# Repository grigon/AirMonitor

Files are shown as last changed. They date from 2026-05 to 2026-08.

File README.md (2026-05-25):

# 🌬️ DIY Air Quality Monitor with Bambu Lab Print Correlation

A self-hosted air quality monitoring station built to track how 3D printing affects indoor air. Measures PM2.5, VOC, and NOx in real time — with live correlation to Bambu Lab printer activity via its local MQTT API.

Built for a flat where a Bambu Lab P2S runs PETG and other filaments regularly.

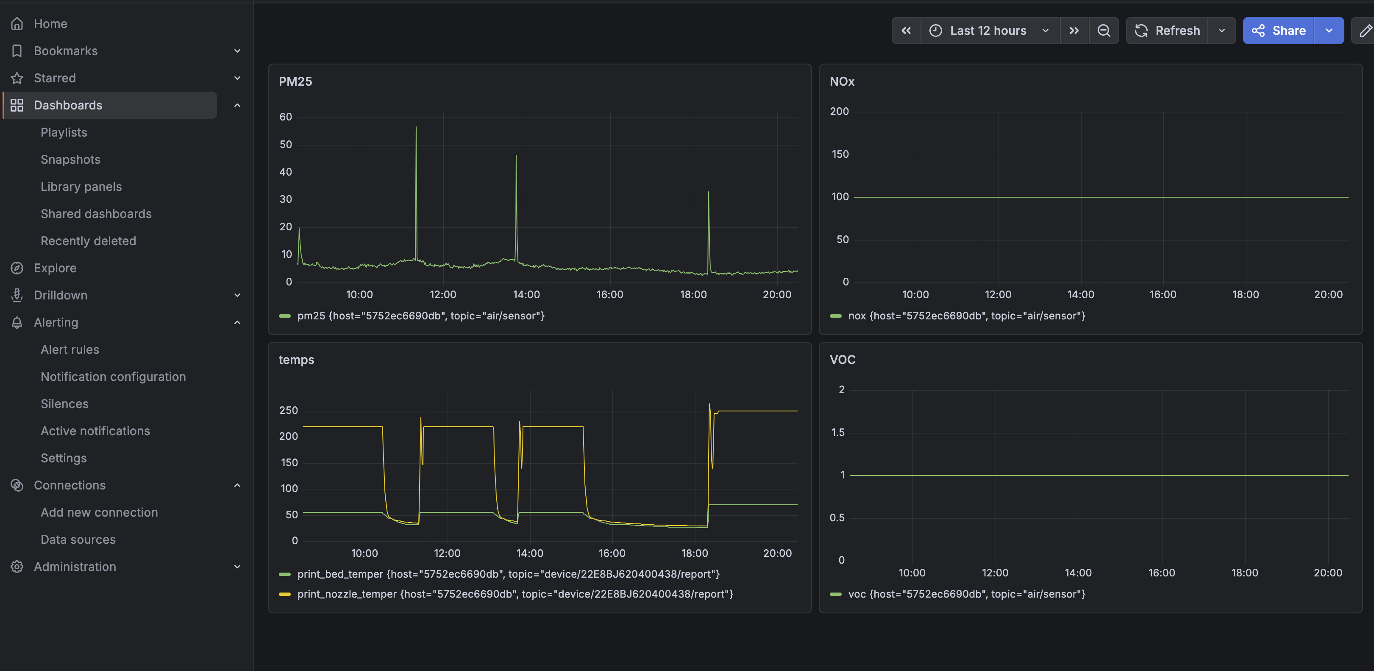
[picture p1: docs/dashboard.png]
Dashboard


---

## Features

- Real-time **PM2.5, PM4, PM10, PM1** via Sensirion SPS30
- **VOC Index and NOx Index** via Sensirion SGP41
- **Bambu Lab printer correlation** — overlays print progress, nozzle/bed temperature with air quality data
- **Email alerts** when air quality thresholds are exceeded
- Fully self-hosted: MQTT → Telegraf → InfluxDB → Grafana
- Runs on a Raspberry Pi with OpenMediaVault (or any Linux server with Docker)

---

## Hardware

| Component | Purpose | Approx. Cost |
| --- | --- | --- |
| ESP32-WROOM-32U (with external antenna) | Microcontroller + WiFi | ~$5 |
| Sensirion SPS30 | Particulate matter (PM1/2.5/4/10) | ~$25 |
| Sensirion SGP41 | VOC + NOx gas sensor | ~$15 |
| External 2.4GHz antenna + U.FL cable | Stable WiFi | ~$3 |
| Breadboard + dupont cables | Prototyping | ~$3 |

> **Note:** For a permanent installation, solder all connections. Loose breadboard connections are a common source of crashes.

---

## Architecture

```
ESP32 (SPS30 + SGP41)
        │
        ▼ MQTT (air/sensor)
Mosquitto Broker ◄──── Bambu Lab P2S (MQTT over SSL)
        │
        ▼
    Telegraf
        │
        ▼
    InfluxDB
        │
        ▼
    Grafana (dashboards + alerts)
```

---

## Wiring

### SGP41 → ESP32 (I2C)

| SGP41 Pin | ESP32 Pin |
| --- | --- |
| VIN | 3.3V |
| GND | GND |
| SDA | GPIO 21 |
| SCL | GPIO 22 |

### SPS30 → ESP32 (I2C via JST ZH 1.5mm 5-pin cable)

| SPS30 Pin | Color (standard cable) | ESP32 Pin |
| --- | --- | --- |
| 1 – VDD | Black | **5V (VIN)** ⚠️ |
| 2 – SDA | Red | GPIO 21 |
| 3 – SCL | White | GPIO 22 |
| 4 – SEL | Yellow | GND (selects I2C mode) |
| 5 – GND | Orange | GND |

> ⚠️ SPS30 requires **5V** on VDD. Both SDA/SCL lines are 3.3V compatible — no level shifter needed.
> ⚠️ Pin 1 color may vary between cable batches. Always verify pin 1 marking (triangle) on the JST connector.

Both sensors share the same I2C bus (GPIO 21/22). I2C addresses:

- SPS30: `0x69`
- SGP41: `0x59`

---

## Software Setup

### 1. Prerequisites

- Docker and Docker Compose installed on your server
- Arduino IDE with ESP32 board support

### 2. Arduino Libraries

Install via Arduino IDE → Library Manager:

- `sps30` by Paul van Haastrecht
- `Sensirion I2C SGP41`
- `Sensirion Core`
- `Sensirion Gas Index Algorithm`
- `PubSubClient`

### 3. Configure and Flash ESP32

Edit `arduino/air_monitor.ino` and set your credentials:

```cpp
const char* ssid = "YOUR_WIFI_SSID";
const char* password = "YOUR_WIFI_PASSWORD";
// ...
mqttClient.setServer("YOUR_SERVER_IP", 1883);
```

Upload to ESP32 via Arduino IDE (`Tools → Board → ESP32 Dev Module`).

### 4. Server Setup (Docker)

Copy `docker/docker-compose.yml` to your server and start services:

```bash
docker compose up -d
```

This starts:

- **Mosquitto** MQTT broker on port 1883
- **InfluxDB 2** on port 8086
- **Grafana** on port 3000
- **Telegraf** data collector

### 5. Configure Mosquitto

Allow anonymous connections (for local network use):

```bash
docker exec -it <mosquitto-container> sh
echo -e "listener 1883\nallow_anonymous true" > /mosquitto/config/mosquitto.conf
exit
docker restart <mosquitto-container>
```

### 6. Configure InfluxDB

1. Open `http://YOUR_SERVER_IP:8086`
2. Create an account, organization (e.g. `home`), and bucket (e.g. `air`)
3. Generate an API token and copy it

### 7. Configure Telegraf

Edit `config/telegraf.conf` with your InfluxDB token, organization, and bucket.

For Bambu Lab integration, add your printer's IP, serial number, and access code (found in printer Settings → Network → LAN Mode).

Restart Telegraf after any config change:

```bash
docker restart <telegraf-container>
```

### 8. Grafana Setup

1. Open `http://YOUR_SERVER_IP:3000` (default: admin/admin)
2. Add InfluxDB as a data source:
   - Query Language: **Flux**
   - URL: `http://influxdb:8086`
   - Organization, token, and default bucket from step 6
3. Create dashboards using the sample queries below

---

## Sample Grafana Queries

### PM2.5 over time

```flux
from(bucket: "air")
  |> range(start: v.timeRangeStart, stop: v.timeRangeStop)
  |> filter(fn: (r) => r._measurement == "mqtt_consumer")
  |> filter(fn: (r) => r._field == "pm25")
  |> aggregateWindow(every: 1m, fn: mean, createEmpty: false)
```

### Bambu Lab nozzle + bed temperature

```flux
from(bucket: "air")
  |> range(start: v.timeRangeStart, stop: v.timeRangeStop)
  |> filter(fn: (r) => r._measurement == "bambu")
  |> filter(fn: (r) => r._field == "print_nozzle_temper" or r._field == "print_bed_temper")
  |> aggregateWindow(every: 1m, fn: mean, createEmpty: false)
```

### Print progress

```flux
from(bucket: "air")
  |> range(start: v.timeRangeStart, stop: v.timeRangeStop)
  |> filter(fn: (r) => r._measurement == "bambu")
  |> filter(fn: (r) => r._field == "print_percent")
  |> aggregateWindow(every: 1m, fn: mean, createEmpty: false)
```

---

## Email Alerts (Grafana)

1. Add SMTP environment variables to Grafana in `docker-compose.yml`:

```yaml
environment:
  - GF_SMTP_ENABLED=true
  - GF_SMTP_HOST=smtp.gmail.com:587
  - GF_SMTP_USER=your@gmail.com
  - GF_SMTP_PASSWORD=your_app_password
  - GF_SMTP_FROM_ADDRESS=your@gmail.com
```

2. In Grafana: **Alerting → Contact points → Add contact point → Email**
3. Create alert rules using the queries below

For Gmail, generate an App Password at `https://myaccount.google.com/apppasswords`.

### Alert Queries

Use time-windowed averages to avoid false alarms from momentary spikes.

**PM2.5** — 30-minute mean (practical for 3D printing; WHO norm is 24h but too slow for episode detection):

```flux
from(bucket: "airmonitor")
  |> range(start: -30m)
  |> filter(fn: (r) => r._measurement == "mqtt_consumer")
  |> filter(fn: (r) => r._field == "pm25")
  |> mean()
```

Threshold: warning `> 15`, alarm `> 35` (µg/m³)

**VOC Index** — 15-minute mean (reacts quickly to filament/solvent emissions):

```flux
from(bucket: "airmonitor")
  |> range(start: -15m)
  |> filter(fn: (r) => r._measurement == "mqtt_consumer")
  |> filter(fn: (r) => r._field == "voc")
  |> mean()
```

Threshold: warning `> 150`, alarm `> 250`

**NOx Index** — 30-minute mean (more stable, slower to change):

```flux
from(bucket: "airmonitor")
  |> range(start: -30m)
  |> filter(fn: (r) => r._measurement == "mqtt_consumer")
  |> filter(fn: (r) => r._field == "nox")
  |> mean()
```

Threshold: warning `> 125`, alarm `> 150`

> **Why different time windows?**
> PM2.5 and NOx change slowly — a 30-minute window smooths noise without losing important trends. VOC reacts faster to short-lived events like filament off-gassing, so a 15-minute window catches episodes before they pass. Using instantaneous readings without mean() causes false alarms from single noisy data points.

---

## Known Issues & Tips

- **SPS30 not initializing on cold boot**: The sensor needs ~30s warmup. The code retries automatically. A hardware watchdog ensures recovery if the I2C bus hangs.
- **VOC baseline**: SGP41 requires ~24 hours of continuous runtime to fully calibrate VOC baseline. Every restart resets the learning algorithm.
- **WiFi stability**: ESP32 PCB antenna struggles with RSSI below -70 dBm. Use a board with an external antenna (WROOM-32U) for reliable operation.
- **SPS30 orientation**: Mount horizontally, label side up. Keep the airflow inlet/outlet unobstructed.

---

## Air Quality Reference

### WHO Air Quality Guidelines (2021)

| Pollutant | Annual mean | 24-hour mean |
| --- | --- | --- |
| **PM2.5** | 5 µg/m³ | 15 µg/m³ |
| **PM10**  | 15 µg/m³ | 45 µg/m³ |
| **NO2** | 10 µg/m³ | 25 µg/m³ |

> Source: [WHO Global Air Quality Guidelines 2021](https://www.who.int/publications/i/item/9789240034228)

### PM2.5 Levels

| PM2.5 (µg/m³) | Level | Notes |
| --- | --- | --- |
| 0–5 | Excellent | Below WHO annual mean |
| 5–15 | Good | Below WHO 24h guideline |
| 15–35 | Moderate  | Exceeds WHO 24h guideline — ventilate |
| 35–75 | Poor | EU limit for daily average |
| >75 | Hazardous | Immediate action recommended |

### VOC & NOx Index (Sensirion Scale)

Sensirion's Gas Index Algorithm outputs a value from 1–500 where **100 = typical clean indoor air baseline**. There is no single WHO standard for VOC as a category.

| Index | Level |
| --- | --- |
| 1–50 | Excellent |
| 51–100  | Good (calibrating baseline) |
| 101–200 | Moderate — increased VOC/NOx detected |
| 201–400 | Poor — ventilate |
| >400 | Hazardous |

### Recommended Alert Thresholds

Based on WHO guidelines, Sensirion documentation, and 3D printing research:

| Metric | Typical indoor range | Warning | Alarm |
| --- | --- | --- | --- |
| PM2.5 | 0–10 µg/m³ | >15 µg/m³ | >35 µg/m³ |
| PM10 | 0–20 µg/m³ | >45 µg/m³ | >75 µg/m³ |
| VOC Index | 80–120 | >150 | >250 |
| NOx Index | 95–105 | >125 | >150 |

> **Why different thresholds for VOC and NOx?**
> VOC Index reacts to a broad range of organic compounds (solvents, filaments, cooking, cleaning products) and has more natural variation. NOx Index is much more stable in typical homes — values above 150 indicate a serious source of nitrogen oxides (combustion, heavy printing). NOx alarm threshold is set lower because elevated NOx is more immediately concerning.

### 3D Printing Context

Studies on FDM printing emissions show:

- **PLA**: relatively low emissions, typically +10–20 µg/m³ PM2.5 near the printer
- **PETG**: moderate emissions, higher VOC than PLA
- **ABS**: high emissions — significant UFP and styrene release
- **TPU**: variable, can be significant

Ventilation is strongly recommended when PM2.5 exceeds 25 µg/m³ during printing.

---

## License

MIT

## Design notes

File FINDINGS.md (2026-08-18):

# Findings: 25 Days of Indoor Air Quality vs 3D Printing

This document summarises a 25-day study (16 May – 11 June 2026) using the monitor in this repo, correlating PM2.5 with Bambu Lab P2S printer activity. Full methodology and statistics are in the accompanying report.

> **TL;DR** — Printing PLA/PETG barely raised PM2.5 above the room's normal background, with or without the VentoBox filter. The biggest particulate events came from outside the printer (cooking / outdoor air). **But once the gas sensor was fixed, the picture changed: VOC rises sharply during printing (+78 index points, p ≈ 7×10⁻¹⁴) — a signal the particle sensor was completely blind to.**

---

## Setup at a glance

- **Sensors:** Sensirion SPS30 (PM1/2.5/4/10) + SGP41 (VOC/NOx) on an ESP32 (external antenna)
- **Pipeline:** ESP32 → MQTT → Telegraf → InfluxDB → Grafana, self-hosted on a Raspberry Pi
- **Printer link:** Bambu Lab P2S status pulled over its local MQTT API (nozzle/bed temp, print state, filtration fan speed)
- **Location matters:** the printer sits near the kitchen and a window — this turns out to be important

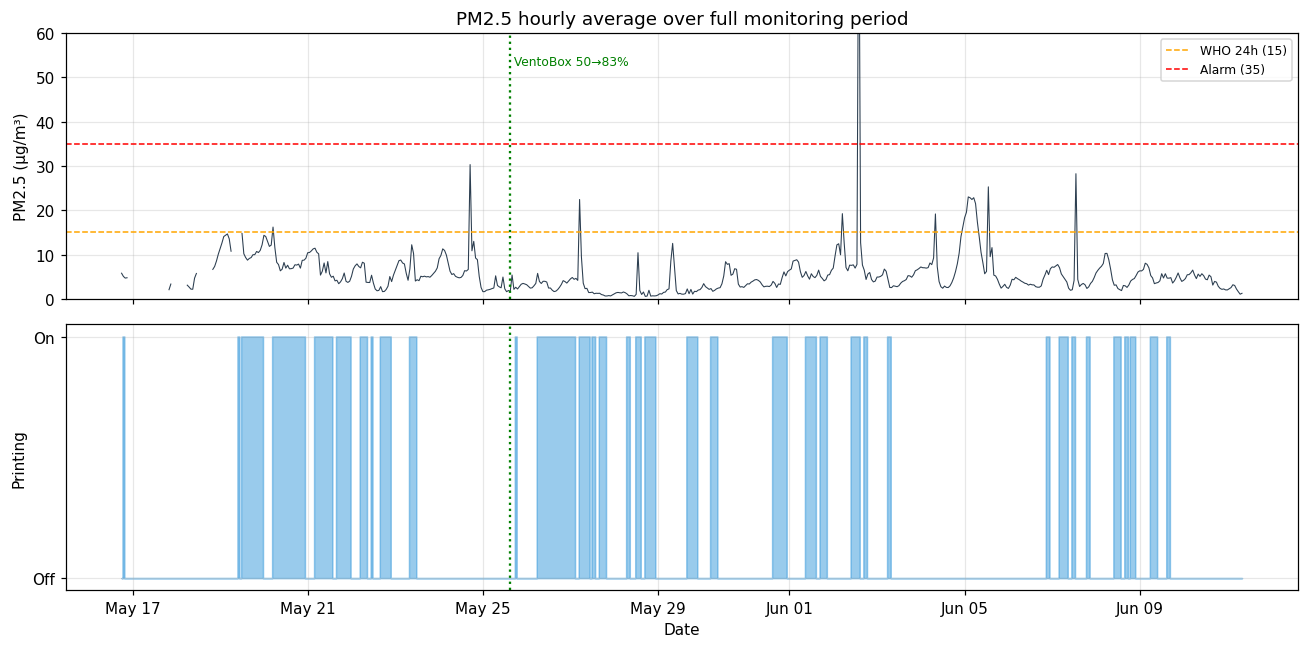
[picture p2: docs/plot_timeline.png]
Timeline


*PM2.5 over the full period with printing activity below. Most of the time the flat sat below the WHO 24-hour guideline (15 µg/m³).*

---

## Finding 1 — Printing barely moves PM2.5

Comparing PM2.5 while printing against the room baseline **within the same period** (so outdoor conditions are held roughly constant), printing added very little:

| Period | Printing median | Baseline median | Difference |
|---|---|---|---|
| No filter (16–24 May) | 6.7 µg/m³ | 6.1 µg/m³ | +0.6 (not significant, p = 0.18) |
| VentoBox (25 May–11 Jun) | 2.9 µg/m³ | 3.6 µg/m³ | −0.7 |

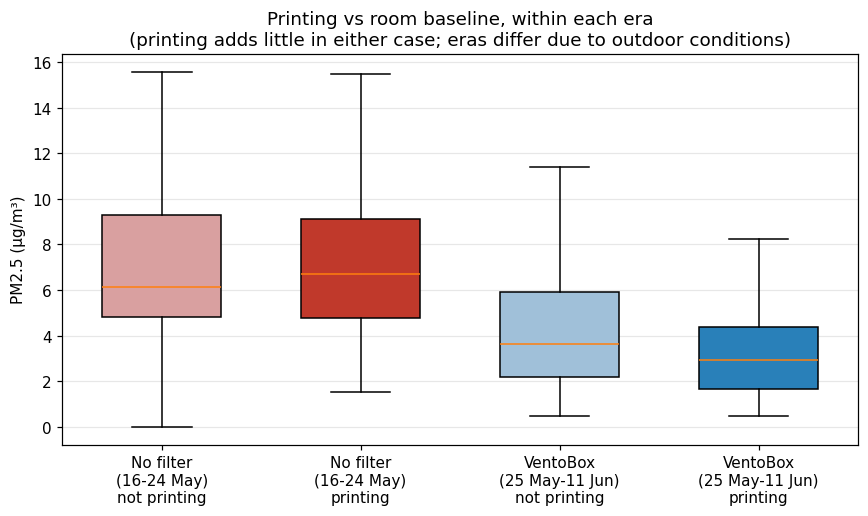
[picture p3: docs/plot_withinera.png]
Within-era comparison


*In both periods the printing and not-printing distributions overlap heavily. The visible shift is **between periods**, not between printing and idle.*

## Finding 2 — The VentoBox benefit can't be isolated (an honest correction)

My first pass found a dramatic "−56% with the VentoBox" result. It was an artifact. The room baseline **with the printer switched off** was 6.1 µg/m³ in mid-May and 3.6 µg/m³ in June — the filter was off during those measurements, so it can't be the cause. Mid-May simply had dirtier outdoor air (daily baselines of 12–13 µg/m³ on 19–21 May).

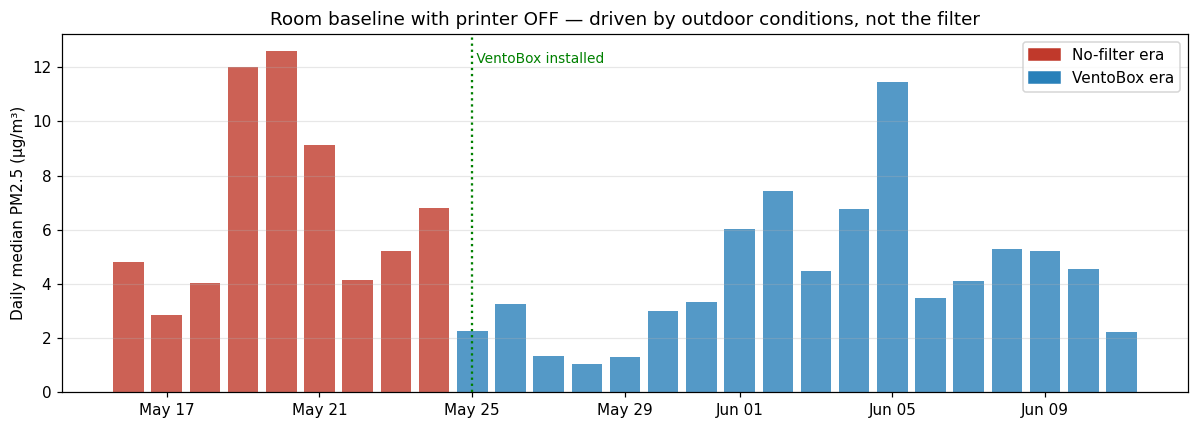
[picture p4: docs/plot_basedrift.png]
Baseline drift


*Room background with the printer OFF — driven by outdoor conditions, not the filter.*

**This does not mean the VentoBox is useless.** The SPS30 only sees particles above ~300 nm and measures no gases. FDM emissions are dominated by ultrafine particles (<100 nm) and VOCs — exactly what a HEPA + activated-carbon filter targets and what this sensor is blind to. The honest conclusion is: *for the PM2.5 this sensor can measure, in this well-ventilated room, the filter's effect is below the noise floor.*

## Finding 3 — PETG emits ~2× the PM2.5 of PLA

Filament type wasn't logged per-print, but nozzle/bed temperature is a clean proxy: PLA clustered at ~220 °C / 55 °C, PETG at ~250 °C / 70 °C (93% of prints classified confidently). Comparing within the VentoBox era, external spikes removed:

| Material | Median PM2.5 | Mean | p90 |
|---|---|---|-----|
| PLA (~220 °C) | 1.7 µg/m³ | 2.7 | 6.0 |
| PETG (~250 °C) | 3.3 µg/m³ | 3.5 | 5.0 |

PETG's median is about double PLA's (p ≈ 2×10⁻¹⁸), consistent with its higher extrusion temperature — but both stayed at or below the room baseline.

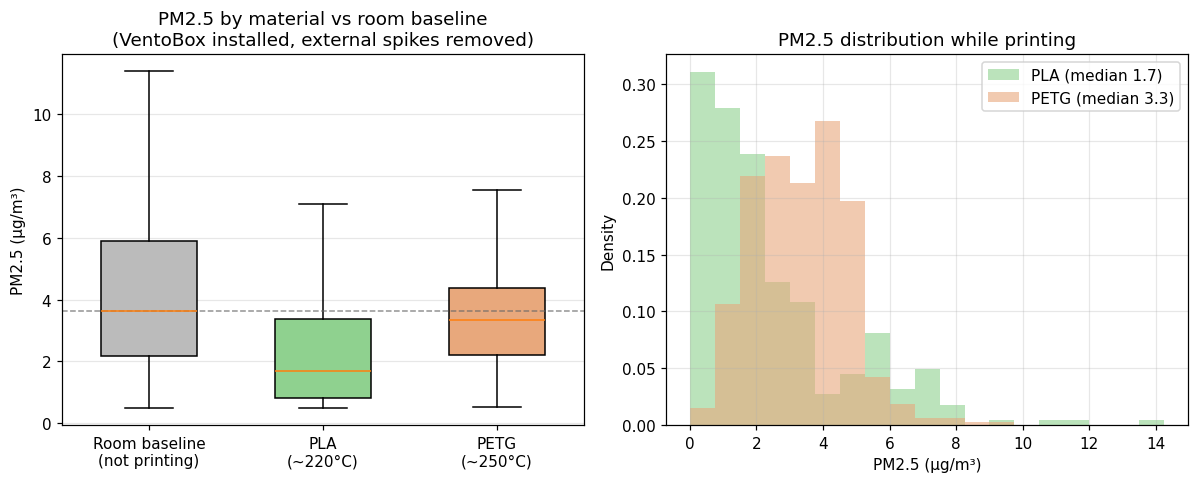
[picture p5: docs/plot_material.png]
Material comparison


## Finding 4 — The real spikes aren't the printer

Eight of the ten highest PM2.5 readings happened while the nozzle was cold. They cluster in the morning and evening — the classic signature of cooking and/or outdoor air entering through the window, given the sensor's location.

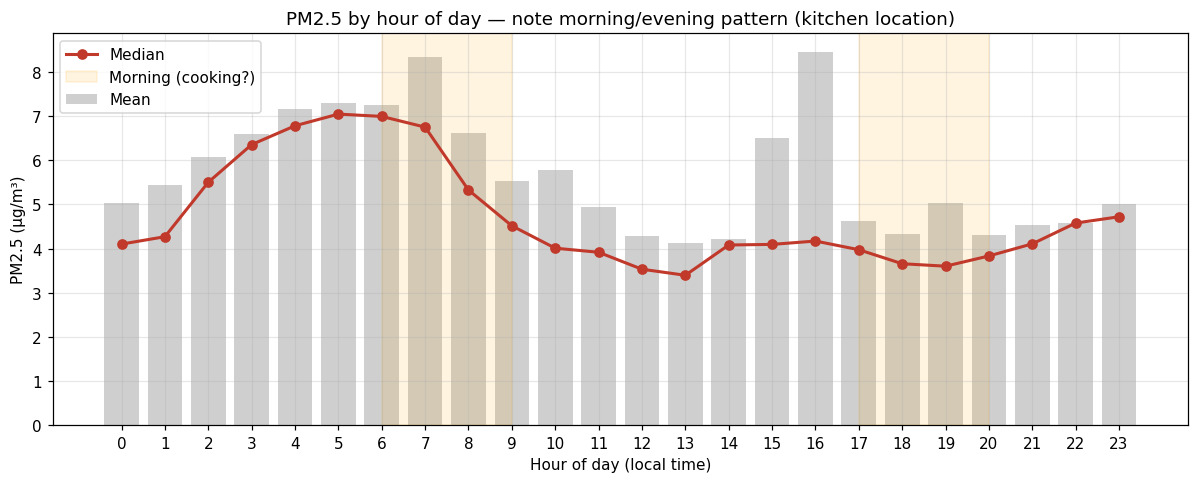
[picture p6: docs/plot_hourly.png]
Hourly pattern


## Finding 5 — Gases tell a completely different story

The first phase had no usable VOC/NOx data. After fixing three separate faults (irregular 1 Hz sampling, a cold solder joint on the sensor's power pin, and transposed algorithm-type constants), a second dataset was collected 25 July – 17 August 2026.

This is where the interesting result lives:

| Channel | Printing | Idle | Difference | p |
|---|---|---|---|---|
| **VOC Index** | 196 | 118 | **+78** | 7×10⁻¹⁴ |
| PM2.5 | 3.2 µg/m³ | 4.1 µg/m³ | −0.9 | 5×10⁻⁵ |
| NOx Index | 1 | 1 | 0 | — |

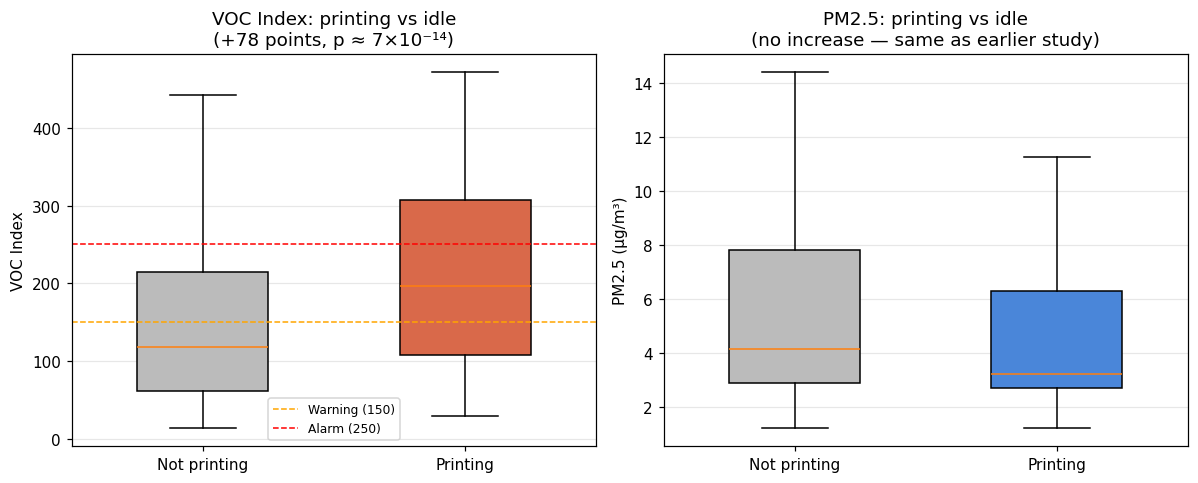
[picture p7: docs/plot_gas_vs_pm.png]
VOC vs PM2.5


*The VOC distribution shifts strongly upward during printing; PM2.5 does not.*

During printing, VOC exceeded 150 **66% of the time** and 250 **36%** — but with the printer *off* those same thresholds were crossed 39% and 21% of the time. The elevation is real, but the distributions overlap heavily.

**Important — what VOC Index is not.** It's not a concentration. The SGP41 produces one signal responding to oxidisable gases collectively, and Sensirion's algorithm converts it to a 1–500 index where 100 = this room's own typical state over the past ~24h. So 200 means "more than usual here," not any µg/m³. VOCs are hundreds of compounds with wildly different toxicity (benzene is carcinogenic; limonene from citrus isn't), which is why **WHO publishes guidelines per compound, not for VOCs as a group** — no threshold here corresponds to a health standard.

The 150/250 thresholds were provisional values picked before any data existed. The data shows they're too low for this room: the idle distribution alone has a 90th percentile of **373**. Better thresholds would come from the room's own idle distribution (e.g. warning 373, alarm 432). That's a monitoring-config fix, not a health finding.

NOx stayed at baseline — expected, since FDM printing doesn't produce nitrogen oxides.

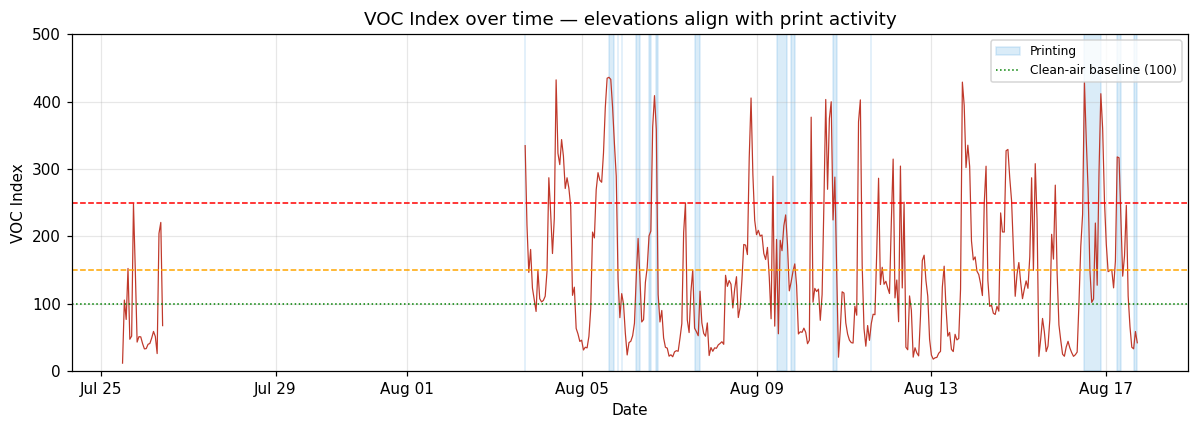
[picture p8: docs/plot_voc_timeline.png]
VOC timeline


**What this means for the filter question:** Finding 2 concluded no PM2.5 benefit from the VentoBox could be demonstrated. The gas data confirms there genuinely *is* a gas-phase signal for an activated-carbon filter to work on. But it doesn't quantify the filter's effect — it ran at 100% continuously through this window, so there's no unfiltered comparison. That needs a deliberate on/off experiment.

**Material comparison stays inconclusive.** Classification was revised (nozzle temperature alone: 195–235 °C = PLA, 235–265 °C = PETG — the old rule requiring a 65 °C+ bed misclassified prints run at 245 °C with a 60 °C bed). In this window PLA had only 39 samples against 240 for PETG. Both raised VOC substantially (+100 and +76), but the difference between them wasn't significant (p = 0.07) and the imbalance is too large to conclude anything.

**Reliability after the fixes:** restarts fell from 29 in 25 days to **two in a month**.

---

---

## What the data could NOT show (and why)

- **VOC / NOx (phase 1):** values sat pinned at their initialisation baseline for the entire first dataset. Three faults were eventually found — irregular algorithm sampling, a cold solder joint intermittently cutting sensor power, and transposed algorithm-type constants. All fixed; results in Finding 5 below.
- **Device stability:** 29 restarts over the period. Diagnostic logging (heap, RSSI, CPU temp, boot reason) showed free heap rock-stable (never below 219 KB) — no memory leak. Restarts were interrupt-watchdog resets from occasional I2C/network blocking, now mitigated with an I2C timeout, bounded reconnects, and regular watchdog servicing.
- **No outdoor reference** sensor, so indoor-vs-outdoor attribution is inferred, not measured.

---

## Enclosure

The sensor lives in a custom 3D-printed enclosure (redesigned for better airflow across the SPS30 inlet/outlet and to keep the SGP41 exposed to room air). Printed on the same P2S it monitors.

Enclosure

<!-- TODO: add enclosure photo at docs/enclosure.jpg -->

---

## Takeaways

1. **Measure the right thing.** Particulates showed nothing; gases showed a clear signal. A PM-only monitor would have concluded "3D printing doesn't affect the air" — and missed the only channel that responds at all. (Whether that signal matters for health is a separate question this sensor can't answer.)
2. In a normally-ventilated room, FDM printing with PLA/PETG had a negligible effect on measurable PM2.5.
3. PETG roughly doubles PM2.5 vs PLA — still low in absolute terms. For VOC, no significant difference was found (small PLA sample).
4. A filter's PM2.5 benefit is hard to prove when printing adds so little to begin with. The gas data shows what it's actually for — but quantifying that needs a matched on/off experiment.
5. Honest measurement means controlling for confounders — the biggest "result" in v1 of this analysis turned out to be the weather.
6. **Log raw sensor signals, not just processed indices.** The gas-index algorithm is stateful and non-invertible, so a month of mislabelled data could not be recovered after the fact.

*Full report with complete statistics and methodology: see `Air_Quality_3D_Printing_Report.docx`.*

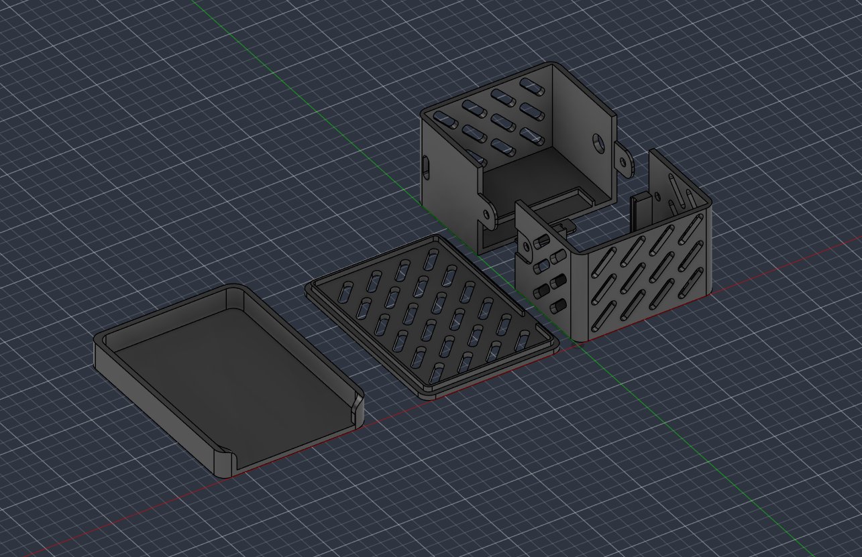
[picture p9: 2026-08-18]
case/model.png

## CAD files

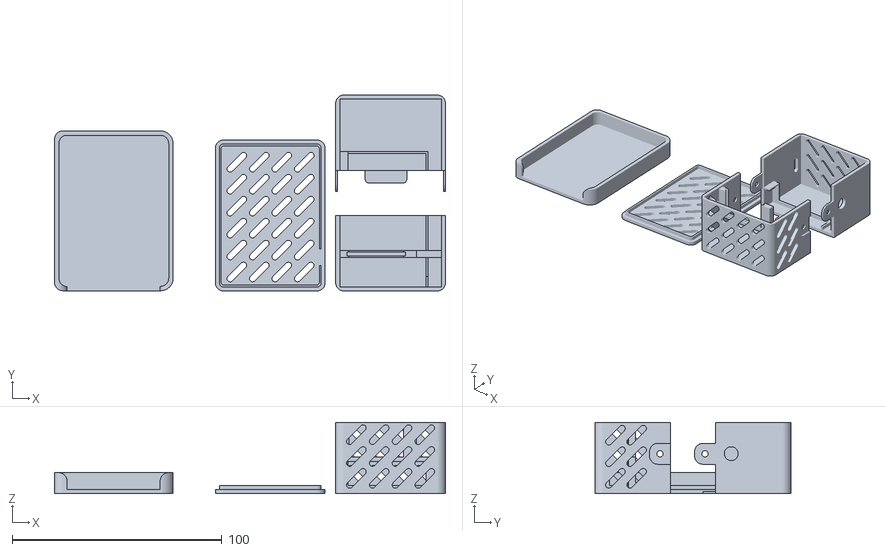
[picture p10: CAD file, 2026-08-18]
case/airmonitor.stl
186.3 x 93.5 x 34.0

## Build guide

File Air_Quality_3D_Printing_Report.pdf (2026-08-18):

# Indoor Air Quality Monitoring

Impact of FDM 3D Printing and Filtration in a Residential Setting
A two-phase self-hosted sensor study · Bambu Lab P2S · Sensirion SPS30 / SGP41

## Executive Summary

This report analyses indoor air quality data collected with a custom-built monitoring station, alongside synchronised operating data from a Bambu Lab P2S 3D printer, in a flat where the printer sits near the kitchen and a window. It covers two phases: an initial 25-day particulate study (16 May – 11 June 2026), and a later gas-phase study (25 July – 17 August 2026) made possible after firmware and hardware faults affecting the gas sensor were diagnosed and fixed. The key findings are:
- Printing PLA or PETG had little measurable effect on PM2.5, with or without filtration. Within each period, particulate levels while printing were statistically indistinguishable from the room baseline when the printer was off.
- The apparent benefit of the VentoBox on PM2.5 could not be isolated. The room baseline itself was lower in the (later) VentoBox period than in the (earlier) no-filter period — even with the printer off — pointing to changing outdoor conditions rather than the filter. The filter’s real value likely lies in gases and ultrafine particles, which this sensor does not measure (see Sections 4 and 7).
- The largest PM2.5 spikes were not caused by the printer. They cluster in the morning and evening and are consistent with cooking and/or outdoor air entering through the window — expected given the sensor's location.
The decisive finding came only after the gas sensor was repaired: VOC rises during printing (median index 196 while printing versus 118 idle, p ≈ 7×10 ¹⁴) — a signal the particulate sensor ⁻ missed entirely. The VOC Index is a relative measure, not a concentration, so this shows that printing changes the air measurably; it does not establish a health risk, and no WHO guideline exists for VOCs as a category. NOx stayed at baseline throughout, as expected for FDM printing. See Section 7.

## 1. Background & Objective

After upgrading from an old RF100 (PLA only) to a Bambu Lab P2S and beginning to print PETG, the motivation was simple: understand what is actually being breathed in a small flat during printing. Commercial air-quality monitors with charting and alerting were expensive, and inexpensive units have a reputation for unreliable readings — so a custom station was built around research-grade Sensirion sensors.
The system streams sensor data over MQTT to a self-hosted stack (Mosquitto, Telegraf, InfluxDB, Grafana) running on a Raspberry Pi. Crucially, the same pipeline also ingests live status from the Bambu Lab P2S over its local MQTT API, allowing air-quality readings to be correlated directly with printer activity, temperatures, and filtration settings.

Indoor Air Quality & 3D Printing — Page 1

## 2. Methodology

### 2.1 Hardware

- ESP32 (WROOM-32U, external antenna) — microcontroller and WiFi link
- Sensirion SPS30 — laser particulate matter sensor (PM1, PM2.5, PM4, PM10)
- Sensirion SGP41 — metal-oxide gas sensor (VOC / NOx index)
- Bambu Lab P2S — print status via local MQTT (nozzle/bed temperature, print state, VentoBox fan speed)

### 2.2 Data collection

Readings were published every few seconds and aggregated to 5-minute means for analysis. The dataset spans 16 May to 11 June 2026 (25 days, 6,781 five-minute samples). Sensor and printer streams were time-aligned to the nearest sample. "Active printing" was defined as nozzle temperature above 150 °C, a reliable indicator of extrusion.
A small number of sensor-startup artefacts (simultaneous zero readings across all channels) were removed prior to analysis.

## 3. Overall Air Quality

Across the full monitoring period, indoor PM2.5 was generally good by WHO standards:

Metric | Value
Mean PM2.5 | 5.7 µg/m³
Median PM2.5 | 4.5 µg/m³
95th percentile | 12.8 µg/m³
Maximum (5-min mean) | 372 µg/m³
Time above WHO 24h guideline (15 µg/m³) | 3.0%
Time above alarm threshold (35 µg/m³) | 0.31%

For context, the WHO 2021 air quality guideline for PM2.5 is an annual mean of 5 µg/m³ and a 24-hour mean of 15 µg/m³. The flat sat below the 24-hour guideline 97% of the time. The rare excursions are examined in Section 5.


Figure 1. Hourly-averaged PM2.5 over the full period (top) with printing activity (bottom). The green dotted line marks the VentoBox installation on 25 May. Orange and red dashed lines are the WHO 24-hour guideline and the chosen alarm threshold.

## 4. The VentoBox: What the Data Can and Cannot Show

The VentoBox filtration unit was installed on 25 May. Before that date the printer ran with no filtration. A natural question is whether the filter reduced printing-related particulates. At first glance the data appears to say yes: median PM2.5 during printing was 6.7 µg/m³ before installation and 2.9 µg/m³ after. However, this comparison is confounded and does not support a causal claim.
The problem is that the room’s background air quality also changed between the two periods — for reasons unrelated to the printer or the filter. Looking only at times when the printer was switched off, the median room baseline was 6.1 µg/m³ during the no-filter period (mid-May) and 3.6 µg/m³ during the VentoBox period (late May to June). Since the printer (and therefore the VentoBox) was off during these measurements, the filter cannot explain the drop. The most likely cause is changing outdoor conditions — mid-May included several visibly polluted days (daily baselines of 12–13 µg/m³ on 19–21 May) while early June was cleaner.

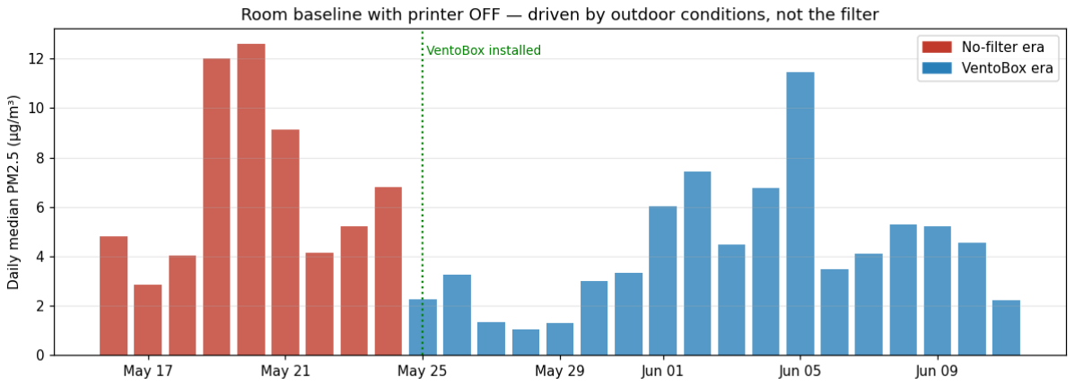
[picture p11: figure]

Figure 2. Daily median PM2.5 with the printer switched off. Because the printer and filter were inactive, this curve reflects the room’s background air — which was higher in mid-May and lower in June, independent of the VentoBox.
The honest way to assess the printer’s impact is to compare printing against the room baseline within the same period, so that outdoor conditions are held roughly constant. Doing this shows printing had a minimal effect in both periods:


Figure 3. PM2.5 while printing versus the room baseline, within each period. In both cases the printing and not-printing distributions overlap heavily; the visible shift is between periods (outdoor conditions), not between printing and idle.
In the no-filter period, printing raised median PM2.5 by just +0.6 µg/m³ over baseline — not statistically significant (Mann-Whitney p = 0.18). In the VentoBox period, printing was actually slightly below baseline. In neither case did printing meaningfully degrade the air.
Conclusion on the VentoBox: this dataset cannot demonstrate a PM2.5 benefit from the filter, because printing barely raised particulates even without it. This does not mean the VentoBox is useless. Two important caveats apply. First, the SPS30 measures particles down to roughly 300 nm and does not capture the ultrafine particles (UFPs, <100 nm) that dominate FDM emissions — a HEPA stage can still help here. Second, the filter’s activated-carbon layer targets gases (VOCs, styrene), which were not measured in this study. The filter may well provide benefits this particulate sensor is simply blind to.

## 5. PLA vs PETG: Does Material Matter?

Although filament type was not logged for each print, nozzle and bed temperatures act as a reliable proxy. The printing data fell into two clean clusters: a low-temperature group (nozzle ~220 °C, bed 55 °C) consistent with PLA, and a high-temperature group (nozzle 245–255 °C, bed 70 °C) consistent with PETG. Using these signatures, 93% of printing samples could be classified confidently.
A fair comparison requires controlling for confounders: PLA was printed more often before the VentoBox was installed, and the dataset contains occasional external pollution spikes unrelated to printing. The comparison below is therefore restricted to the period after VentoBox installation, with external events (PM2.5 > 50 µg/m³) excluded.


Figure 4. PM2.5 by material versus the room baseline (VentoBox installed, external spikes removed). PETG prints show roughly double the median PM2.5 of PLA, but both stay at or below the non-printing room baseline (dashed line).
The result has two parts. First, PETG does emit more particulates than PLA: its median PM2.5 during printing (3.3 µg/m³) is about twice that of PLA (1.7 µg/m³), a highly significant difference (p ≈ 2×10 ¹⁸). This matches expectations, since PETG is extruded around 30 °C hotter. Second ⁻ — and more reassuring — with the VentoBox running, neither material pushed PM2.5 above the normal room baseline (3.6 µg/m³). PLA printing actually sat about 1.9 µg/m³ below baseline and PETG about 0.3 µg/m³ below it.
In other words, the difference between PLA and PETG is real but small in absolute terms, and the filtration is effective enough that printing either material did not measurably degrade the air relative to the room’s usual state. The higher PETG figure is best read as “less strongly filtered below baseline,” not as a hazardous level.

## 6. What Actually Drives the Spikes

Counter to initial expectations, the printer was not the main source of high PM2.5 readings. Of the ten highest 5-minute readings, eight occurred while the nozzle was cold (not printing). The top five events:

Time (UTC) | PM2.5 | Printing?
2 Jun 14:30 | 372 µg/m³ | Yes
2 Jun 14:35 | 300 µg/m³ | No
2 Jun 14:40 | 240 µg/m³ | No
24 May 17:55 | 185 µg/m³ | No
5 Jun 13:10 | 171 µg/m³ | No

The single highest reading does coincide with printing, but it is immediately followed by even larger readings after the nozzle cooled — suggesting an external event (e.g. cooking, a window opened to a smoggy street) that happened to overlap the end of a print, rather than being caused by it.


Figure 5. PM2.5 by hour of day (local time). The pronounced early-morning and evening pattern is characteristic of cooking and/or outdoor air ingress — consistent with the sensor's placement near the kitchen and a window — rather than printing, which occurred at varied hours.
Because the sensor sits near the kitchen and a window, two plausible external sources are cooking emissions and outdoor air (including seasonal smog). Distinguishing the two would require an outdoor reference sensor and is left for future work.

## 7. Gas-Phase Results: What the Particle Sensor Missed

The original study could not analyse VOC and NOx because a firmware sampling bug prevented the Sensirion gas-index algorithm from calibrating (see Section 8.1). That bug was fixed, and a second fault was later found: the algorithm type constants were transposed, so each channel was processed with the wrong algorithm. After correcting both, a fresh dataset was collected from 25 July to 17 August 2026 (4,287 five-minute samples, of which 321 during active printing). Three days where the VOC channel froze at a constant value were excluded. The gas data changes the headline conclusion of this report. Where particulates showed no printing signal at all, VOC rises sharply and unambiguously during printing:

Channel | Printing (median) | Idle (median) | Difference | p-value
VOC Index | 196 | 118 | +78 | 7×10 ¹⁴ ⁻
PM2.5 | 3.2 µg/m³ | 4.1 µg/m³ | −0.9 | 5×10 ⁵⁻
NOx Index | 1 | 1 | 0 | —

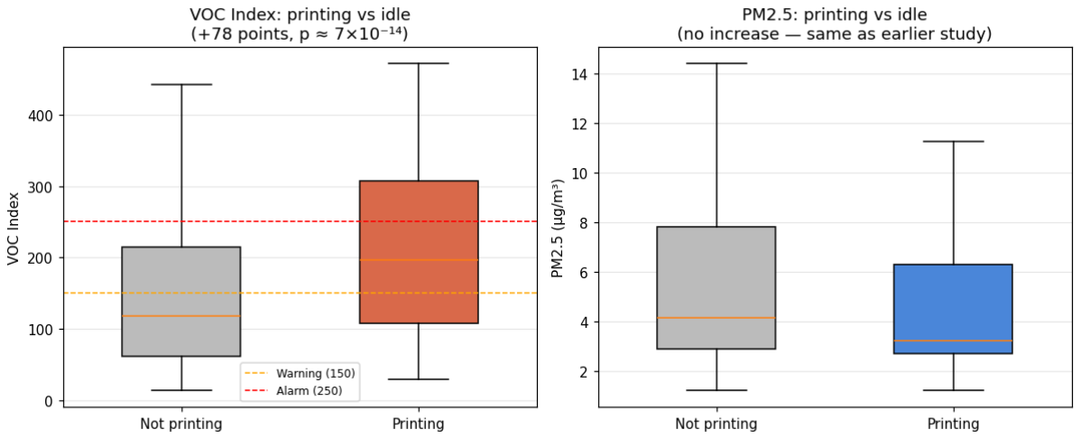
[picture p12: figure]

Figure 6. VOC Index and PM2.5 compared between printing and idle periods. The VOC distribution shifts strongly upward during printing, crossing the 150 warning threshold; PM2.5 shows no such shift. Dashed lines mark the VOC warning (150) and alarm (250) levels.
During printing the VOC Index exceeded 150 for 66% of the time and 250 for 36%. Those figures need their counterpart to be read correctly: with the printer switched off the same thresholds were exceeded 39% and 21% of the time. The elevation during printing is real, but the two distributions overlap substantially — this is not a case of clean air punctuated by printing events. The NOx Index remained at its clean-air baseline of 1 throughout, which is expected, as FDM printing does not produce nitrogen oxides.

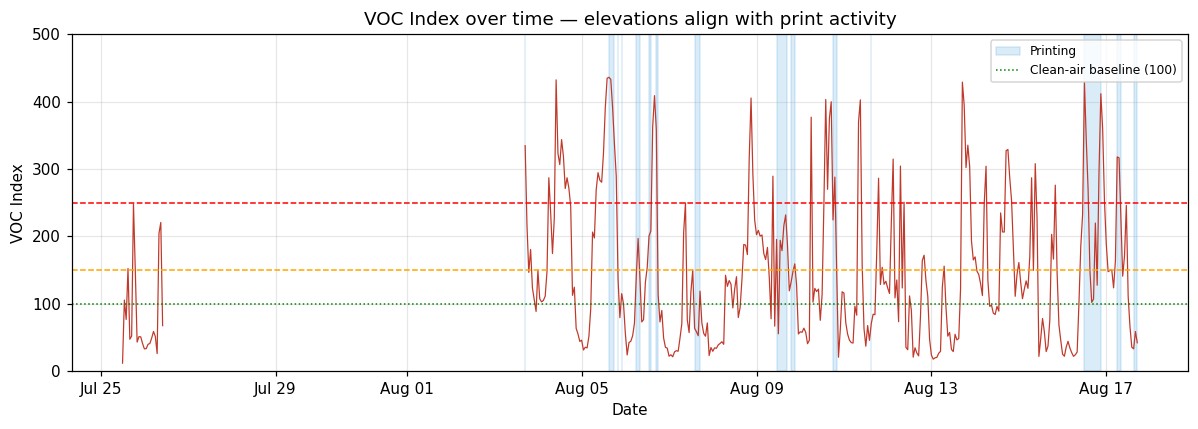
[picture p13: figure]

Figure 7. VOC Index over the measurement window, with printing periods shaded. Sustained elevations align with print activity; the green dotted line marks the nominal clean-air baseline of 100.

### 7.1 How to read these numbers — and how not to

The VOC Index is not a concentration and cannot be compared against health limits. The SGP41 is a metal-oxide sensor: it produces a single signal that responds to oxidisable gases collectively, with no ability to identify which compounds are present or in what quantity. Sensirion’s algorithm converts that signal into a 1–500 index in which 100 represents the room’s own typical state over roughly the preceding 24 hours. A reading of 200 therefore means "more oxidisable gas than is usual here," not any particular µg/m³.
This matters because volatile organic compounds are a category of hundreds of substances with vastly different toxicity — benzene and formaldehyde are carcinogens with strict limits;

limonene from citrus is essentially harmless. For that reason the WHO publishes guidelines for individual compounds, not for VOCs as a group, and no threshold in this report corresponds to a health standard. Distinguishing filament off-gassing from cooking, cleaning products, or solvents would require compound-specific instrumentation.
The 150 and 250 thresholds used above were chosen as provisional operational values before any data existed. The data now shows they are too low for this room: the idle distribution alone has a 90th percentile of 373. Thresholds set from the room’s own idle distribution (for example warning at 373 and alarm at 432) would flag genuinely unusual conditions rather than ordinary daily variation. This is a monitoring-configuration conclusion, not a health finding.
What can be said from this dataset: printing produces a measurable, statistically robust gas-phase signal that the particulate sensor does not detect at all. What cannot be said: whether that signal represents a health risk. Answering that requires measuring specific compounds against their own guideline values.

### 7.2 Why this matters for the VentoBox

Section 4 concluded that no PM2.5 benefit from the VentoBox could be demonstrated, while noting that the filter’s activated-carbon layer targets gases the sensor could not measure. The gas data confirms that a gas-phase signal from printing genuinely exists and is substantial. It does not, however, quantify the filter’s effect: throughout this window the VentoBox ran continuously at 100%, so there is no unfiltered comparison period. Establishing the filter’s VOC benefit would require a deliberate experiment — matched prints of the same material with the filter on and off.

### 7.3 Material comparison remains inconclusive

Filament classification was revised for this phase. The earlier study required PETG to have a bed temperature of 65 °C or above, which misclassified a large group of prints run at 245 °C nozzle with a 60 °C bed. Since nozzle temperature is the reliable discriminator, classification now uses it alone: 195–235 °C for PLA and 235–265 °C for PETG.
In this window PLA accounted for only 39 printing samples against 240 for PETG. Both materials raised VOC substantially above baseline (PLA +100, PETG +76 index points), but the difference between them was not statistically significant (p = 0.07) and the sample imbalance is too large to support a conclusion. The finding to take from this phase is that both materials off-gas measurably, not that one is worse than the other.
This also does not overturn the particulate result from Section 5, which was based on a better-balanced sample and found PETG produced roughly twice the PM2.5 of PLA. Gases and particles behave differently, and there is no reason to expect the same ranking.

### 7.4 Device reliability after the fixes

Stability improved markedly. A cold solder joint on the gas sensor’s power pin — which had been intermittently cutting power and resetting the algorithm baseline — was repaired. Combined with the firmware changes, restarts fell from 29 in 25 days to just two in the month following the fix, both RTC watchdog resets.

## 8. Limitations & Future Work

### 8.1 Gas-phase data: the original fault

During the first phase, VOC and NOx values remained pinned at their initialisation values (VOC = 1, NOx = 100) with zero variance, even across a continuous 30-hour window. Three separate faults were eventually found. First, the Sensirion gas-index algorithm requires its processing function to be called at a steady 1 Hz, but the original firmware called it irregularly, so the algorithm never built its internal baseline. Second, a cold solder joint on the sensor’s power pin intermittently cut power, resetting whatever baseline had accumulated. Third, the algorithm type constants were transposed in the constructor, so each channel was processed with the other’s algorithm — which is why the two baselines appeared swapped once data finally began to vary. All three were corrected: the gas sensor is now sampled on a dedicated, unconditional 1-second timer; the power pin was resoldered; and the algorithm types were fixed. The resulting data is analysed in Section 7. A lesson for future work: the raw sensor signals should also be logged alongside the computed indices, since the index algorithm is stateful and non-invertible — with only the processed values stored, the mislabelled data from the first phase could not be recovered.

### 8.2 Device reliability

Diagnostic logging (free heap, RSSI, CPU temperature, boot reason) was used to characterise stability. Over the period the device restarted on 29 occasions. Boot-reason analysis showed an early cluster (18–19 May) of power-cycles and WiFi-loss restarts during active development, followed by periodic interrupt-watchdog resets every 1–3 days. Free heap was rock-stable throughout (never below 219 KB, drift ≈ −5 bytes/hour), ruling out a memory leak; the watchdog resets are attributed to occasional blocking on the I2C bus or network calls. The revised firmware adds an I2C timeout, bounded reconnect attempts, and regular watchdog servicing to address this.

### 8.3 Other limitations

- No outdoor reference sensor, so indoor-vs-outdoor attribution of spikes is inferred, not measured.
- Filament type (PLA vs PETG) was not logged per-print, so material-specific emission differences could not be isolated.
- 5-minute averaging smooths short transient events; high-resolution capture would better resolve brief emission peaks.

## 9. Conclusions

- Indoor PM2.5 in the flat was good overall, below the WHO 24-hour guideline 97% of the time.
- Printing PLA or PETG barely raised PM2.5 above the room baseline — even without filtration (+0.6 µg/m³, not significant). A clear PM2.5 benefit from the VentoBox could not be isolated, because the printer added so little to begin with.
- The VentoBox should not be dismissed. The gas-phase data confirms a substantial VOC signal from printing — precisely what an activated-carbon filter targets — but the filter ran continuously throughout that phase, so its benefit remains unquantified. A matched on/off experiment is the obvious next step.

- PETG produced about twice the median PM2.5 of PLA while printing (3.3 vs 1.7 µg/m³), consistent with its higher extrusion temperature — but with the VentoBox running, both materials stayed at or below the room baseline.
- The largest pollution events originated outside the printer, consistent with cooking and outdoor air given the sensor location.
- Gas-phase monitoring, once working, revealed what the particulate sensor could not: printing raises the VOC Index by roughly 78 points above the idle median. Both PLA and PETG off-gas measurably. Because the index is relative rather than a concentration, this establishes that printing alters the air — not that it is hazardous; the provisional 150/250 thresholds proved too low for this room and should be reset from its own idle distribution.

Data collected 16 May – 11 June 2026. Analysis based on 6,781 five-minute samples of sensor data time-aligned with 4,652 printer status records. Hardware: ESP32 + Sensirion SPS30/SGP41; pipeline: MQTT → Telegraf → InfluxDB → Grafana.

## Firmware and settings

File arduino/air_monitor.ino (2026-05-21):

#include <Wire.h>
#include <SensirionI2CSgp41.h>
#include <SensirionGasIndexAlgorithm.h>
#include <sps30.h>
#include <WiFi.h>
#include <PubSubClient.h>
#include <esp_system.h>
#include <esp_task_wdt.h>
#include "soc/soc.h"
#include "soc/rtc_cntl_reg.h"

// ── Configuration ─────────────────────────────────────────────────────────────
const char* ssid     = "YOUR_WIFI_SSID";
const char* password = "YOUR_WIFI_PASSWORD";
const char* mqttHost = "YOUR_SERVER_IP";
const int   mqttPort = 1883;
// ──────────────────────────────────────────────────────────────────────────────

WiFiClient espClient;
PubSubClient mqttClient(espClient);

SensirionI2CSgp41 sgp41;
SPS30 sps30;
SensirionGasIndexAlgorithm vocAlgorithm(1);
SensirionGasIndexAlgorithm noxAlgorithm(2);

// ── MQTT reconnect ────────────────────────────────────────────────────────────
void reconnectMQTT() {
  int attempts = 0;
  while (!mqttClient.connected() && attempts < 10) {
    Serial.println("Connecting to MQTT...");
    if (mqttClient.connect("esp32-air")) {
      Serial.println("MQTT connected");
    } else {
      Serial.printf("MQTT failed (rc=%d), retry in 5s\n", mqttClient.state());
      delay(5000);
      attempts++;
    }
  }
}

// ── Diagnostics ───────────────────────────────────────────────────────────────
void sendDiagnostics() {
  String diag = "{\"heap\":"    + String(ESP.getFreeHeap()) +
                ",\"rssi\":"    + String(WiFi.RSSI()) +
                ",\"uptime\":"  + String(millis() / 1000) +
                ",\"wifi\":"    + String(WiFi.status()) +
                ",\"mqtt\":"    + String(mqttClient.connected()) +
                ",\"cpu_temp\":" + String(temperatureRead()) + "}";
  mqttClient.publish("air/diagnostics", diag.c_str());
}

// ── Setup ─────────────────────────────────────────────────────────────────────
void setup() {
  WRITE_PERI_REG(RTC_CNTL_BROWN_OUT_REG, 0); // disable brownout reset

  Serial.begin(115200);
  delay(5000); // give sensors time to power up on cold boot

  // I2C with timeout to prevent bus hangs
  Wire.begin(21, 22); // SDA, SCL
  Wire.setTimeOut(1000);

  sgp41.begin(Wire);
  sps30.begin(I2C_COMMS);
  sps30.start();

  // Connect to WiFi
  WiFi.begin(ssid, password);
  Serial.print("Connecting to WiFi");
  while (WiFi.status() != WL_CONNECTED) {
    delay(500);
    Serial.print(".");
  }
  Serial.printf("\nConnected! IP: %s\n", WiFi.localIP().toString().c_str());

  // Connect to MQTT
  mqttClient.setServer(mqttHost, mqttPort);
  reconnectMQTT();

  // Send boot reason (useful for diagnosing unexpected restarts)
  String bootReason = "{\"boot_reason\":" + String(esp_reset_reason()) + "}";
  mqttClient.publish("air/diagnostics", bootReason.c_str());
  Serial.println("Boot reason sent: " + bootReason);

  // Hardware watchdog — restart ESP32 if loop() hangs for >30 seconds
  esp_task_wdt_config_t wdt_config = {
    .timeout_ms  = 30000,
    .idle_core_mask = 0,
    .trigger_panic  = true
  };
  esp_task_wdt_init(&wdt_config);
  esp_task_wdt_add(NULL);
}

// ── Loop ──────────────────────────────────────────────────────────────────────
void loop() {
  esp_task_wdt_reset(); // feed the watchdog

  // WiFi reconnect
  if (WiFi.status() != WL_CONNECTED) {
    Serial.println("WiFi lost, reconnecting...");
    WiFi.disconnect();
    WiFi.begin(ssid, password);
    int tries = 0;
    while (WiFi.status() != WL_CONNECTED && tries < 20) {
      delay(500);
      tries++;
    }
    if (WiFi.status() != WL_CONNECTED) {
      Serial.println("WiFi failed, restarting...");
      esp_restart();
    }
  }

  // MQTT reconnect
  if (!mqttClient.connected()) {
    reconnectMQTT();
  }
  mqttClient.loop();

  // Send diagnostics every cycle
  sendDiagnostics();

  // ── SGP41 ────────────────────────────────────────────────────────────────
  uint16_t srawVoc, srawNox;
  sgp41.measureRawSignals(0x8000, 0x8000, srawVoc, srawNox);
  int32_t vocIndex = vocAlgorithm.process(srawVoc);
  int32_t noxIndex = noxAlgorithm.process(srawNox);

  // ── SPS30 ────────────────────────────────────────────────────────────────
  struct sps_values val;
  sps30.GetValues(&val);

  if (val.MassPM2 == 0.0) {
    Serial.println("SPS30 not ready, reinitializing...");
    sps30.begin(I2C_COMMS);
    sps30.start();
    delay(5000);
    return;
  }

  // ── Publish sensor data ───────────────────────────────────────────────────
  String payload = "{\"pm25\":"  + String(val.MassPM2) +
                   ",\"pm10\":"  + String(val.MassPM10) +
                   ",\"pm1\":"   + String(val.MassPM1) +
                   ",\"pm4\":"   + String(val.MassPM4) +
                   ",\"voc\":"   + String(vocIndex) +
                   ",\"nox\":"   + String(noxIndex) + "}";

  mqttClient.publish("air/sensor", payload.c_str());
  Serial.println("Published: " + payload);

  delay(1000);
}

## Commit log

2026-05-21 project setup
    [airmonitor.stl]
2026-08-18 update report and model
    [airmonitor.stl]
